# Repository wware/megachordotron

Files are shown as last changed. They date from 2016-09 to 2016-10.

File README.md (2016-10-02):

The Megachordotron
====

The Megachordotron is a
[MIDI controller](https://en.wikipedia.org/wiki/MIDI_controller)
organized around simple
[chords](https://en.wikipedia.org/wiki/Chord_(music)). It's
intended for people (like myself) who are too clumsy to play a guitar.

A demonstration (https://www.youtube.com/watch?v=67fjFGl2Ubo)

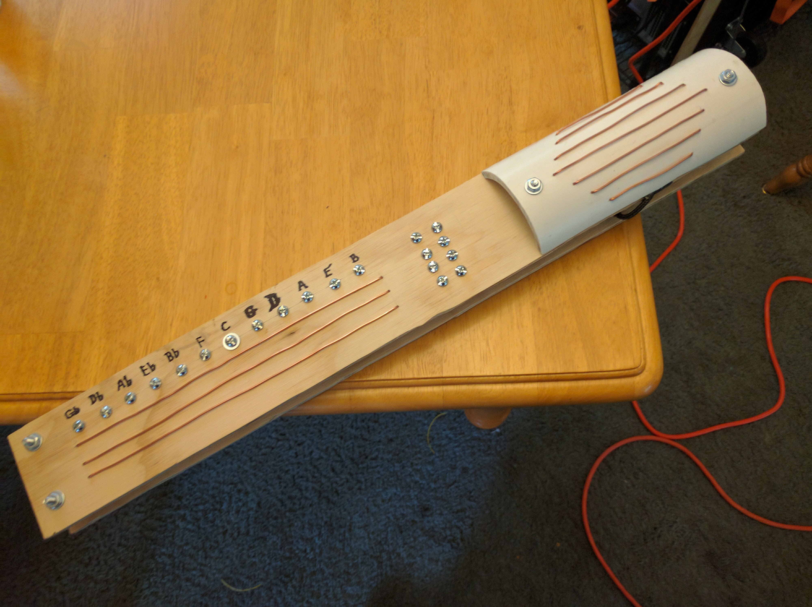
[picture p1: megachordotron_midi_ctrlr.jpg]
A picture of the Megachordotron


Since it's just a MIDI controller, it needs a
[MIDI synthesizer](https://en.wikipedia.org/wiki/MIDI#Synthesizers) to work.
The synthesizer is the PC on this little rack, which is a
[Linux Mint](https://www.linuxmint.com/) box running Fluidsynth (here is
[some](https://wiki.archlinux.org/index.php/FluidSynth)
[info](http://tedfelix.com/linux/linux-midi.html) about that).
There is also a guitar amp and a keyboard and monitor.

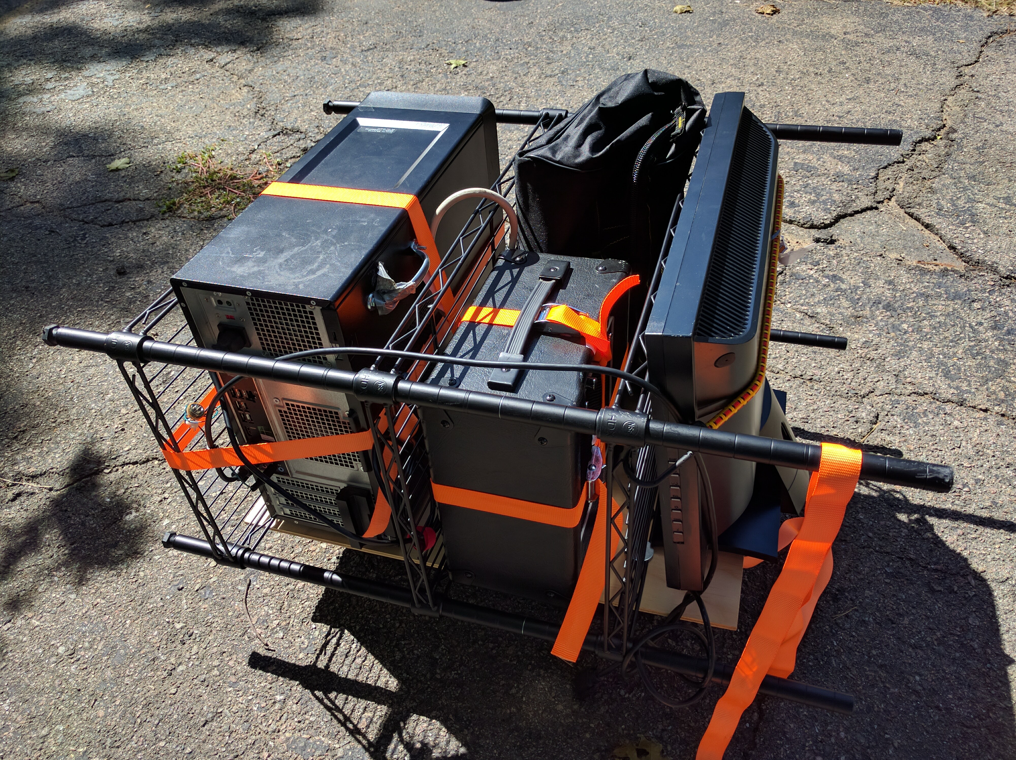
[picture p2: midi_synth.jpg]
The MIDI synth as of 10/1/2016


After Maker Faire is over, I want to spend some time making the synth much
[less cumbersome](http://www.tomsguide.com/us/best-mini-pcs,review-2760.html).
As it stands it is quite inconvenient.

BTW, the shortened URL for this repository is https://git.io/vPt04.

Printed circuit board
----

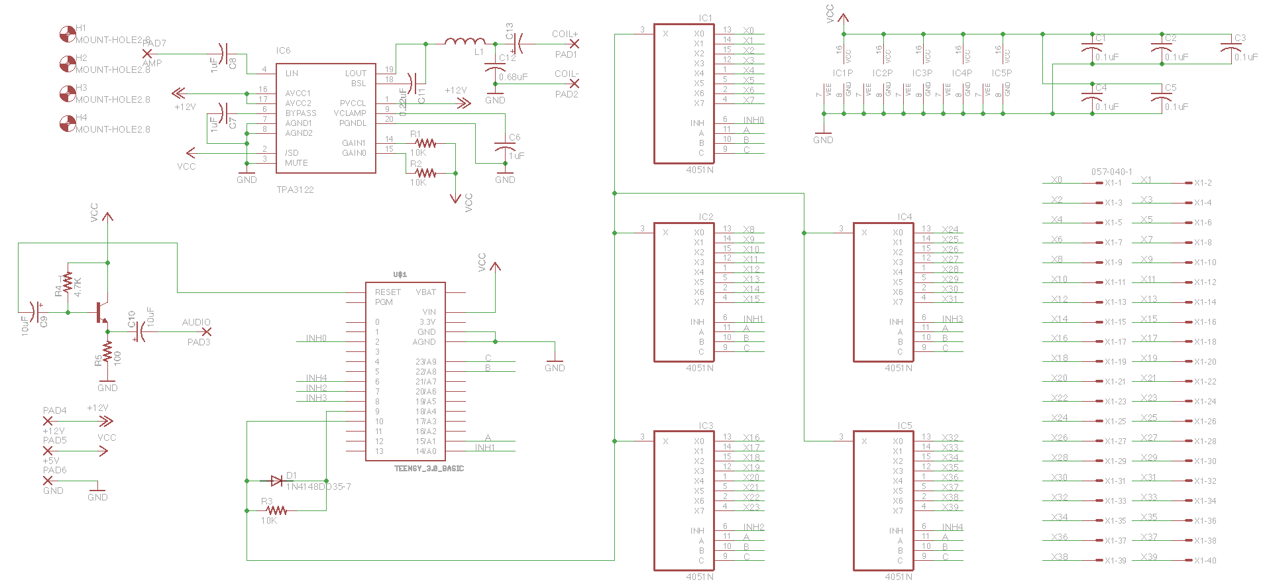
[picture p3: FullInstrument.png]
Schematic


I use Cadsoft Eagle for PCB layout. For these designs you'll need to pick up
some third-party libraries.

* [Teensy 3.0 library](https://forum.pjrc.com/attachment.php?attachmentid=184&d=1358973338)
  - [Discussion of Teensy library](https://www.pjrc.com/teensy/eagle_lib.html)
* [Sparkfun Connector library](https://github.com/sparkfun/SparkFun-Eagle-Libraries)

Errata
----

I laid out the board in haste and made a mistake. One end of the diode D1 does not
connect correctly to the resistor R3. I think it's the cathode. I had to solder a
little jumper.

This board was originally used for a different instrument (hence the filename) and
the audio circuitry is not needed in the current instantiation. There is no need to
populate the TPA3122 (IC6) or the emitter follower to the left, or the parts around
them, or the last CD4051 (IC5). There is also no need to supply +12V or +5V other
than what is supplied by the USB cable.

The bypass caps should all be populated, and D1 and R3 must be populated.

Programming the Teensy
----

You should use a Teensy 3.1 or 3.2 to build the Megachordotron.

In the Arduino application menu, choose `Tools > USB Type`, and select `MIDI`.

I am running my Teensy at 72 MHz, but that's probably something you can experiment
with. There is only one place in the code where fast timing is really significant,
in the `read_kdy` function in `teensy.ino` which is mostly in assembly language.
Actually now that I think of it, I'll probably switch to 96 MHz, because that
affects keyboard sensitivity.

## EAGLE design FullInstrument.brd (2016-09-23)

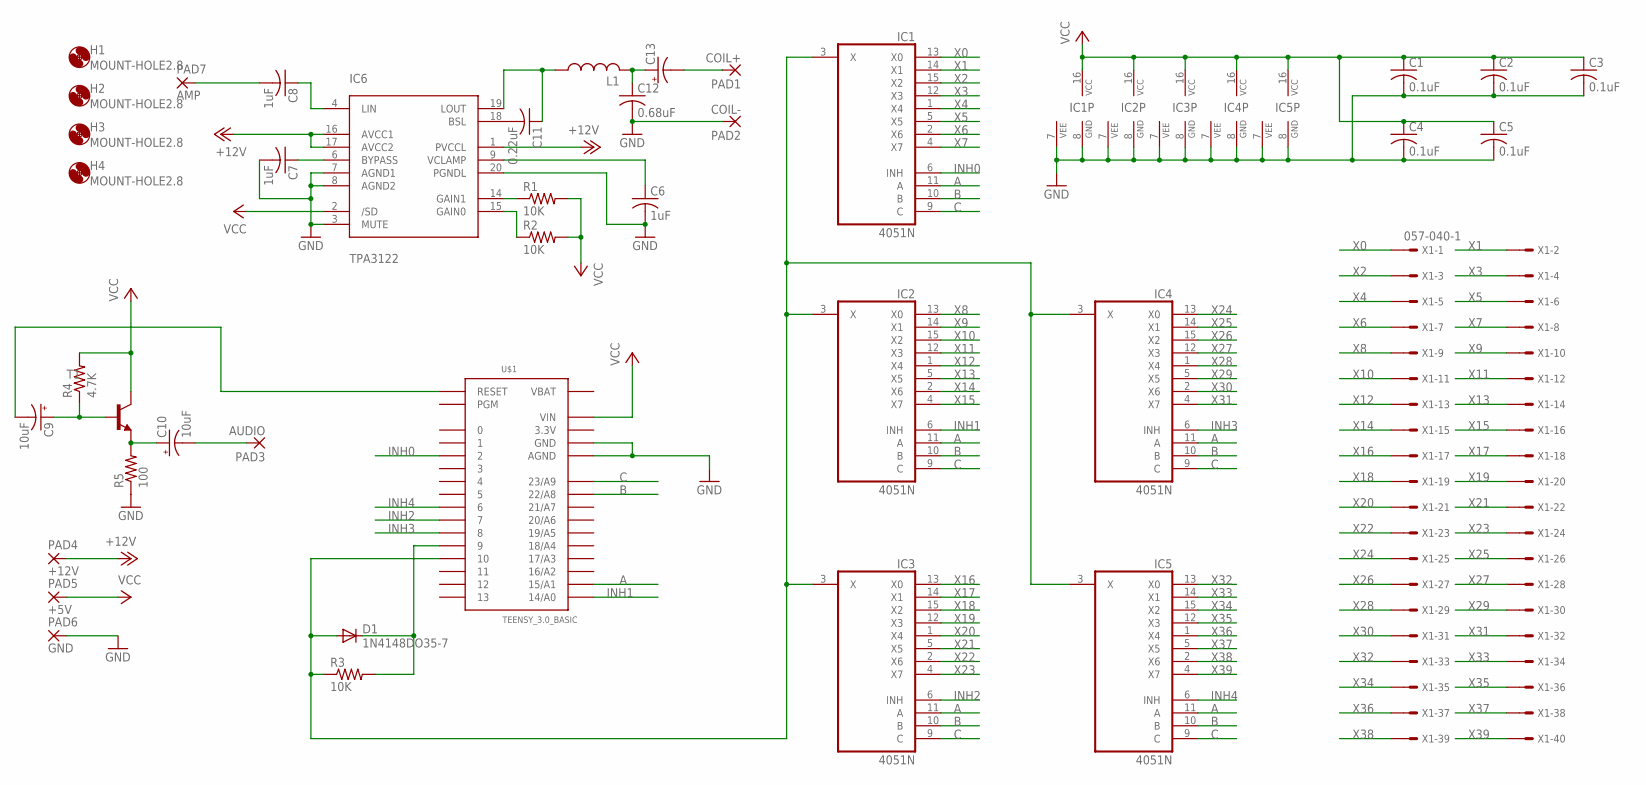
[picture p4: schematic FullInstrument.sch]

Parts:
C1, C2, C3, C4, C5: 0.1uF; C025-025X050
C6, C7, C8: 1uF; C050-025X075
C9, C10: 10uF; E2-5
C11: 0.22uF; C050-025X075
C12: 0.68uF; C050-025X075
C13: CPOL-USE5-8.5; E5-8,5
D1: 1N4148DO35-7; DO35-7
H1, H2, H3, H4: MOUNT-HOLE2.8; 2,8
IC1, IC2, IC3, IC4, IC5: 4051N; DIL16
IC6: TPA3122; TPA3122-DIP20
L1: L-US6000-XXX-RC; 6000-XXXX-RC
PAD1: COIL+; 3,17/1,3
PAD2: COIL-; 3,17/1,3
PAD3: AUDIO; 3,17/1,3
PAD4: +12V; 3,17/1,3
PAD5: +5V; 3,17/1,3
PAD6: GND; 3,17/1,3
PAD7: AMP; 3,17/1,3
R1, R2, R3: 10K; 0204V
R4: 4.7K; 0204V
R5: 100; 0204V
T1: -NPN-TO92-EBC; TO92-EBC
U$1: TEENSY_3.0_BASIC
X1: 057-040-1

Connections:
3.3V: U$1.3.3V, U$1.3.3V1 (3.3V)
+12V: IC6.1 (PVCCL), IC6.16 (AVCC1), IC6.17 (AVCC2), PAD4.1
A: IC1.11 (A), IC2.11 (A), IC3.11 (A), IC4.11 (A), IC5.11 (A), U$1.15/A1
B: IC1.10 (B), IC2.10 (B), IC3.10 (B), IC4.10 (B), IC5.10 (B), U$1.22/A8
C: IC1.9 (C), IC2.9 (C), IC3.9 (C), IC4.9 (C), IC5.9 (C), U$1.23/A9
GND: C1.2, C2.2, C3.2, C4.2, C5.2, C6.2, C7.2, C12.2, IC1.7 (VEE), IC1.8 (GND), IC2.7 (VEE), IC2.8 (GND), IC3.7 (VEE), IC3.8 (GND), IC4.7 (VEE), IC4.8 (GND), IC5.7 (VEE), IC5.8 (GND), IC6.3 (MUTE), IC6.7 (AGND1), IC6.8 (AGND2), IC6.20 (PGNDL), PAD2.1, PAD6.1, R5.1, U$1.AGND, U$1.GND, U$1.GND1 (GND)
INH0: IC1.6 (INH), U$1.2
INH1: IC2.6 (INH), U$1.14/A0
INH2: IC3.6 (INH), U$1.7
INH3: IC4.6 (INH), U$1.8
INH4: IC5.6 (INH), U$1.6
unnamed: IC6.14 (GAIN1), R1.1
unnamed: C11.2, IC6.18 (BSL)
unnamed: IC6.15 (GAIN0), R2.1
unnamed: C8.1, IC6.4 (LIN)
unnamed: C7.1, IC6.6 (BYPASS)
unnamed: C6.1, IC6.9 (VCLAMP)
unnamed: R3.2, U$1.9
unnamed: D1.A, IC1.3 (X), IC2.3 (X), IC3.3 (X), IC4.3 (X), IC5.3 (X), R3.1, U$1.10
unnamed: C10.+, R5.2, T1.E
unnamed: C9.+, R4.1, T1.B
unnamed: C11.1, IC6.19 (LOUT), L1.1
unnamed: C9.-, U$1.RESET
unnamed: C12.1, C13.+, L1.2
unnamed: C13.-, PAD1.1
unnamed: C10.-, PAD3.1
unnamed: C8.2, PAD7.1
VBAT: U$1.VBAT
VCC: C1.1, C2.1, C3.1, C4.1, C5.1, IC1.16 (VCC), IC2.16 (VCC), IC3.16 (VCC), IC4.16 (VCC), IC5.16 (VCC), IC6.2 (/SD), PAD5.1, R1.2, R2.2, R4.2, T1.C, U$1.VIN
X0: IC1.13 (X0), X1.1
X1: IC1.14 (X1), X1.2
X2: IC1.15 (X2), X1.3
X3: IC1.12 (X3), X1.4
X4: IC1.1 (X4), X1.5
X5: IC1.5 (X5), X1.6
X6: IC1.2 (X6), X1.7
X7: IC1.4 (X7), X1.8
X8: IC2.13 (X0), X1.9
X9: IC2.14 (X1), X1.10
X10: IC2.15 (X2), X1.11
X11: IC2.12 (X3), X1.12
X12: IC2.1 (X4), X1.13
X13: IC2.5 (X5), X1.14
X14: IC2.2 (X6), X1.15
X15: IC2.4 (X7), X1.16
X16: IC3.13 (X0), X1.17
X17: IC3.14 (X1), X1.18
X18: IC3.15 (X2), X1.19
X19: IC3.12 (X3), X1.20
X20: IC3.1 (X4), X1.21
X21: IC3.5 (X5), X1.22
X22: IC3.2 (X6), X1.23
X23: IC3.4 (X7), X1.24
X24: IC4.13 (X0), X1.25
X25: IC4.14 (X1), X1.26
X26: IC4.15 (X2), X1.27
X27: IC4.12 (X3), X1.28
X28: IC4.1 (X4), X1.29
X29: IC4.5 (X5), X1.30
X30: IC4.2 (X6), X1.31
X31: IC4.4 (X7), X1.32
X32: IC5.13 (X0), X1.33
X33: IC5.14 (X1), X1.34
X34: IC5.15 (X2), X1.35
X35: IC5.12 (X3), X1.36
X36: IC5.1 (X4), X1.37
X37: IC5.5 (X5), X1.38
X38: IC5.2 (X6), X1.39
X39: IC5.4 (X7), X1.40

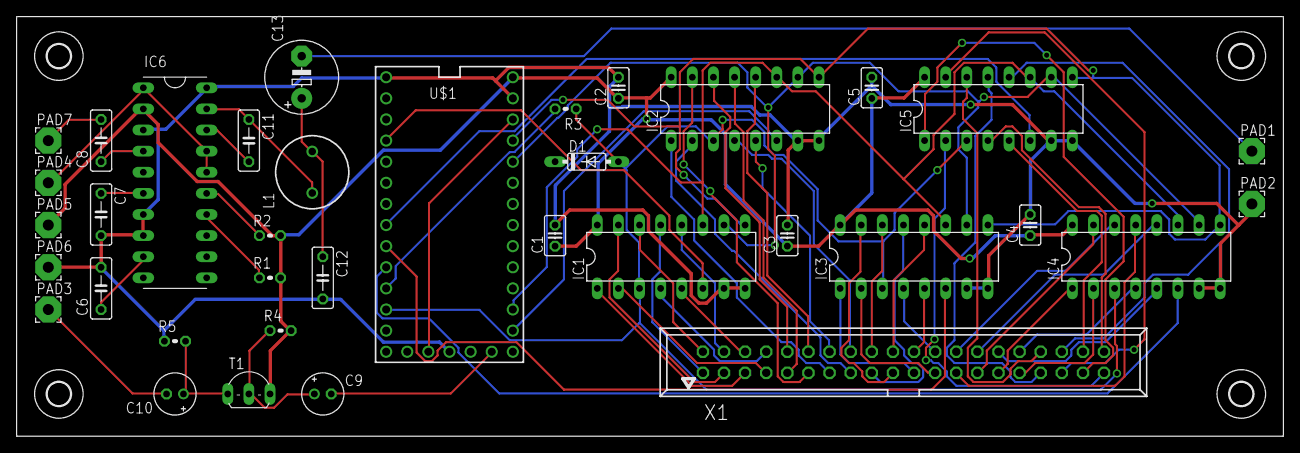
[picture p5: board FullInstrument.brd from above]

Board: 2 copper layers, 152.4 x 50.5 mm, 40 parts (0 on the bottom side), 68 nets.

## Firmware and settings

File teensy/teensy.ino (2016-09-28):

/**
 * Arduino/Teensy settings:
 *   Teensy 3.2 / 3.1
 *   USB Type: MIDI  (nothing additional)
 *   CPU Speed: 72 MHz
 */

extern unsigned char chord_table[];

#include "keys.h"

// Something is wonky about the eight high-numbered key connections
// on this PC board, probably some kind of assembly error, but the
// lower 32 are working OK.
#define NUM_KEYS 30

#define DIAGNOSTICS 0

#define PIANO            0
#define CELESTA         10
#define TUBULAR_BELLS   14
#define CHURCH_ORGAN    19
#define NYLON_GUITAR    24
#define CELLO           42
#define ORCHESTRAL_HARP 46
#define CHOIR_AAHS      52
#define TRUMPET         56
#define SYNTH_BRASS     62
#define ALTO_SAX        65
#define FLUTE           73

uint8_t voices[] = {
    PIANO, CELESTA, CHURCH_ORGAN, NYLON_GUITAR,
    CELLO, CHOIR_AAHS, TRUMPET, FLUTE
};

#define INH0  2
#define INH1  14
#define INH2  7
#define INH3  8
#define INH4  6

uint32_t inhibits[] = {INH0, INH1, INH2, INH3, INH4};

#define A_SELECT 15
#define B_SELECT 22
#define C_SELECT 23

/**
 * A pointer into chord_table, where we find the pitches for the sevn
 * strings.
 */
uint8_t *chord_pointer = &chord_table[7 * 6];

/**
 * If we want to transpose the chord up or down by some number of octaves,
 * do that here. This should be a multiple of 12.
 */
int8_t chord_transpose = 0;

// Port A, Port C, Port D
uint32_t port_settings[2 * NUM_KEYS];

#define PORT_A 0x400FF000
#define PORT_C 0x400FF080
#define PORT_D 0x400FF0C0

static inline uint32_t read_key(uint32_t X, uint32_t Y, uint32_t portc) {
    // offset 4 is set output
    // offset 8 is clear output
    // offset 16 is read input
    asm volatile(
        // digitalWrite(9, LOW);
        "mov %0, #0x08"                 "\n"
        "str %0, [%2, #8]"              "\n"

        // X = 20;
        "mov %0, #20"                   "\n"

        // while (X > 0) X--;
        "1:"                            "\n"
        "subs %0, %0, #1"               "\n"
        "bne 1b"                        "\n"

        // digitalWrite(9, HIGH);
        "mov %0, #0x08"                 "\n"
        "str %0, [%2, #4]"              "\n"

        // while (Y > 0) Y--;
        "2:"                            "\n"
        "subs %1, %1, #1"               "\n"
        "bne 2b"                        "\n"

        // X = digitalReadFast(10);
        "ldr %0, [%2, #16]"             "\n"
        "ands %0, %0, #0x10"            "\n"

        // digitalWrite(9, LOW);
        "mov %1, #0x08"                 "\n"
        "str %1, [%2, #8]"              "\n"
        : "+r" (X), "+r" (Y), "+r" (portc)
    );
    return !X;
}

void flash_int(int n)
{
    int i = n / 5;
    n -= 5 * i;
    while (i--) {
        digitalWrite(LED_BUILTIN, HIGH);
        delayMicroseconds(1000 * 1000);
        digitalWrite(LED_BUILTIN, LOW);
        delayMicroseconds(200 * 1000);
    }
    while (n--) {
        digitalWrite(LED_BUILTIN, HIGH);
        delayMicroseconds(200 * 1000);
        digitalWrite(LED_BUILTIN, LOW);
        delayMicroseconds(200 * 1000);
    }
}


int h = 0;

class Key : public BaseKey
{
public:
    Key(uint32_t _id) : BaseKey(_id) {}

    bool read_n(uint32_t n) {
        digitalWrite(A_SELECT, (id & 1) ? HIGH : LOW);
        digitalWrite(B_SELECT, (id & 2) ? HIGH : LOW);
        digitalWrite(C_SELECT, (id & 4) ? HIGH : LOW);
        unsigned int i;
        for (i = 0; i < 5; i++) {
            if (i == (id >> 3))
                digitalWrite(inhibits[i], LOW);
            else
                digitalWrite(inhibits[i], HIGH);
        }
        return read_key(0, n, PORT_C);
    }
};

class StringKey : public Key
{
public:
    StringKey(uint32_t _id) : Key(_id) {}

    /**
     * The pitch of the most recent key_down event.
     */
    int8_t last_pitch;

    void keydown(void) {
        int8_t pitch = chord_pointer[id];
        usbMIDI.sendNoteOn(pitch, 127, 1);
        last_pitch = pitch;
    }

    void keyup(void) {
        usbMIDI.sendNoteOff(last_pitch, 0, 1);
    }
};

Key *keyboard[NUM_KEYS];
uint8_t program;

KeySelect chord_base_select(6);
KeyGroup chord_modifier_group(0);
KeySelect program_select(0);

void setup() {
    uint8_t j;

    pinMode(LED_BUILTIN, OUTPUT);

    uint8_t i;

    pinMode(10, INPUT_PULLUP);
    pinMode(9, OUTPUT);
    digitalWrite(9, LOW);
    pinMode(2, OUTPUT);
    pinMode(6, OUTPUT);
    pinMode(7, OUTPUT);
    pinMode(8, OUTPUT);
    pinMode(14, OUTPUT);
    pinMode(15, OUTPUT);
    pinMode(22, OUTPUT);
    pinMode(23, OUTPUT);

    for (i = 0; i < NUM_KEYS; i++) {
        if (i < 7)
            keyboard[i] = new StringKey(i);
        else
            keyboard[i] = new Key(i);
    }

    for (i = 7; i < 19; i++)
        chord_base_select.add(keyboard[i]);
    for ( ; i < 22; i++)
        chord_modifier_group.add(keyboard[i]);
    for ( ; i < 30; i++)
        program_select.add(keyboard[i]);

    for (i = 0; i < NUM_KEYS; i++) {
        keyboard[i]->fresh_calibrate();
    }

    for (j = 0; j < 3; j++) {
        for (i = 0; i < NUM_KEYS; i++) {
            keyboard[i]->calibrate();
        }
    }

    program = 0;
    for (i = 0; i < 5; i++) {
        usbMIDI.sendProgramChange(voices[program], 1);
        delayMicroseconds(100 * 1000);
    }
}

void loop(void) {
    int i;

    for (i = 7; i < NUM_KEYS; i++)
        keyboard[i]->check();

    chord_base_select.scan();
    chord_modifier_group.scan();
    program_select.scan();

    int8_t cbs = chord_base_select.any_pressed();
    int8_t cmg = chord_modifier_group.any_pressed();
    int8_t ps = program_select.any_pressed();

    /*
     * 1 means major, 2 means minor, 4 means maj7, 6 means min7.
     * The value ends up always being even so we can right-shift
     * and use a smaller lookup table.
     */
    static int8_t modifier = 1;

    switch (chord_modifier_group.value()) {
        default:
        case 0:
        case 3:
        case 5:
        case 7:
            break;
        case 1:
            modifier = 1;
            break;
        case 2:
            if (modifier != 6)
                modifier = 2;
            break;
        case 4:
            if (modifier != 6)
                modifier = 4;
            break;
        case 6:
            modifier = 6;
            break;
    }

    if (cbs || cmg) {
        uint8_t *new_chord_pointer = &chord_table[
            7 * (
                12 * (modifier >> 1) + chord_base_select.value()
            )
        ];

        if (new_chord_pointer != chord_pointer) {
            chord_pointer = new_chord_pointer;
            for (i = 0; i < 7; i++) {
                if (keyboard[i]->state &&
                    chord_pointer[i] != ((StringKey*)keyboard[i])->last_pitch) {
                    keyboard[i]->keyup();
                    keyboard[i]->keydown();
                }
            }
        }
    }

    // select the instrument
    if (ps && !program_select.previous_pressed()) {
        digitalWrite(LED_BUILTIN, HIGH);
        int8_t p = program_select.value();
        if (p != program) {
            usbMIDI.sendProgramChange(voices[p], 1);
            program = p;
        }
    }
    else digitalWrite(LED_BUILTIN, LOW);

    chord_base_select.update();
    chord_modifier_group.update();
    program_select.update();

    for (i = 0; i < 7; i++)
        keyboard[i]->check();
}
